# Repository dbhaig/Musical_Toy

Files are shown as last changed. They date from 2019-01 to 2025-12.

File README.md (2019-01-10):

# Musical Toy

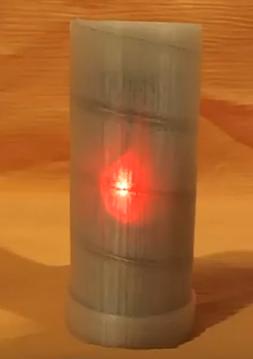
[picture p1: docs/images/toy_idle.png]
Toy in idle state

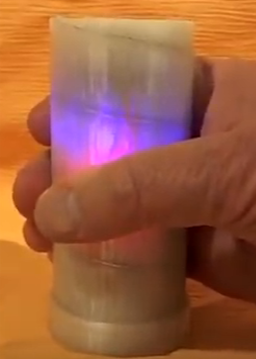
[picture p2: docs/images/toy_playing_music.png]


This repository contains the files needed to construct an inexpensive toy
that plays audio files when held. 

This toy was developed in response to a
request made from Makers Making Change:

https://www.makersmakingchange.com/project/conductive-touch-music-toy/

A video of the toy can be found here: https://www.youtube.com/watch?v=sac93CFT064

## Firmware

The toy uses an Arduino Nano to control a DFPlayer Mini MP3 player.  [Firmware Details](firmware/README.md)

## Bill of Materials

Item # | Description                                   | Qty | Source
-------|-----------------------------------------------|----------|-------
   1   | Arduino Nano (V3)                             |  1  | E Bay
   2   | DFPlayer Mini                                 |  1  | E Bay
   3   | 9V Battery Enclosure w/ Power Switch          |  1  | E Bay
   4   | Breadboard Friendly PCB Speaker - 8 Ohm, 0.2W |  1  | www.BuyaPi.ca / www.adafruit.com
   5   | 4GB - 32 GB SD Card                           |  1  | www.BuyaPi.ca
   6   | 9 Volt Battery                                |  1  |

## 3D Printed Parts

Item # | Description                                   
-------|-----------------------------------------------------------------------
   1   | Outer shell with embedded 24 AWG wire - acts a capacitive touch sensor [stl file](enclosure/stl_files/shell.stl)
   2   | Arduino Nano Holder [stl file](enclosure/stl_files/arduino_nano_clip.stl)
   3   | Clip to hold Speaker [stl file](enclosure/stl_files/speaker_clip.stl)
   4   | Frame to hold DFPlayer Mini, Nano frame and 9V enclosure [stl file](enclosure/stl_files/9V_surround.stl)
   5   | End Cap [stl file](enclosure/stl_files/cap.stl)

3D printed parts were designed to by printed using a 0.4mm nozzle. [Enclosure Details](enclosure/README.md)

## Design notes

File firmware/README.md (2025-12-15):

# Arduino Firmware

The firmware is written using the following libraries:

* ADCTouch by martin2250 - https://github.com/martin2250/ADCTouch 
* DFPlayer by DFRobot - https://github.com/DFRobot/DFRobotDFPlayerMini 

The firmware is fairly straight forward. The Arduino can be programmed using the IDE found here:
https://www.arduino.cc/en/main/software

The touch sensitivity of the toy can be adjusted by changing the value of the 
touch_ambient variable.

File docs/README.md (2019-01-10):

# Documentation

## Wiring Diagram

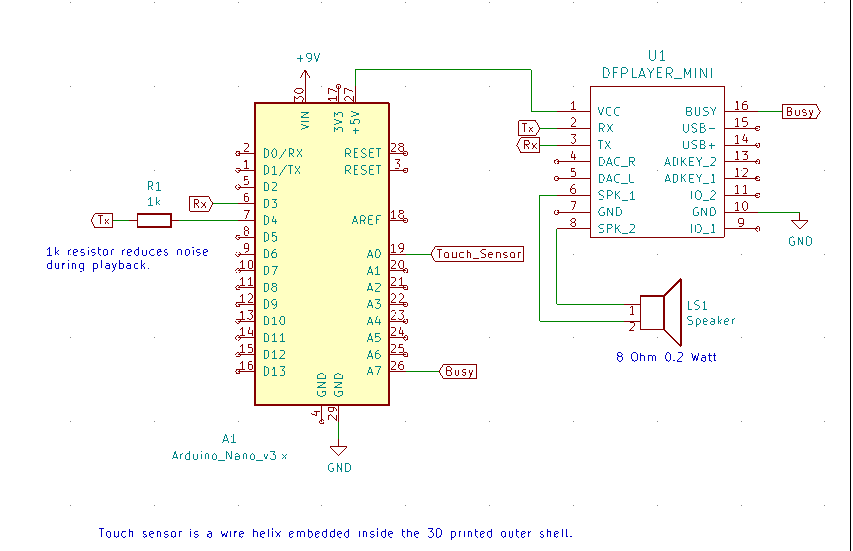
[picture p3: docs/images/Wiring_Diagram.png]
Wiring Diagram


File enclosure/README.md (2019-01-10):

# 3D Printed Parts

## Design Software

The 3D printed part were designed using OpenSCAD version 2015.03-2 (http://www.openscad.org/)

## Assembly

Exploded view:

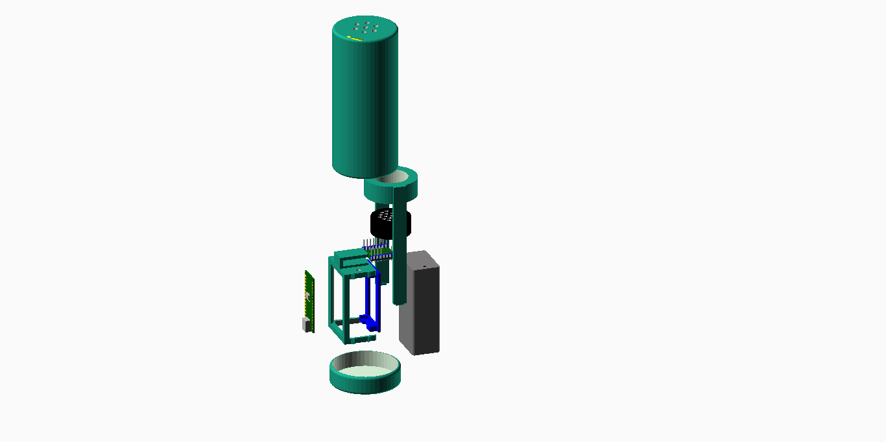
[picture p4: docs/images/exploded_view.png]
Exploded View


Interior Assembly:

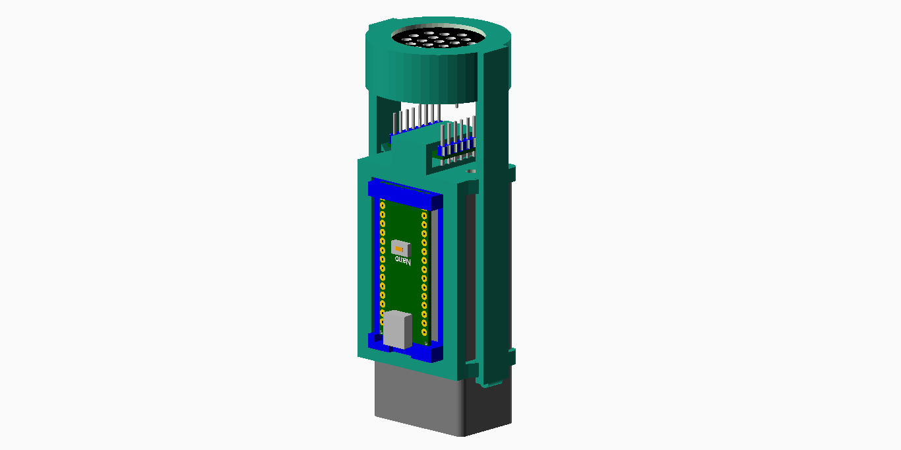
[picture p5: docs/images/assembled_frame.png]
Interior Assembly


The arduino nano holder (blue) should be glued to the frame (turquoise) using hot glue or super glue.

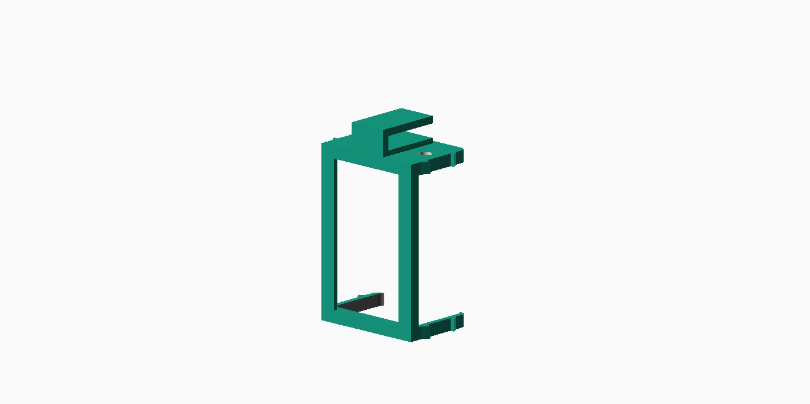
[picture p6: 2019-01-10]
docs/images/battery_clip+dfplayer_holder.png

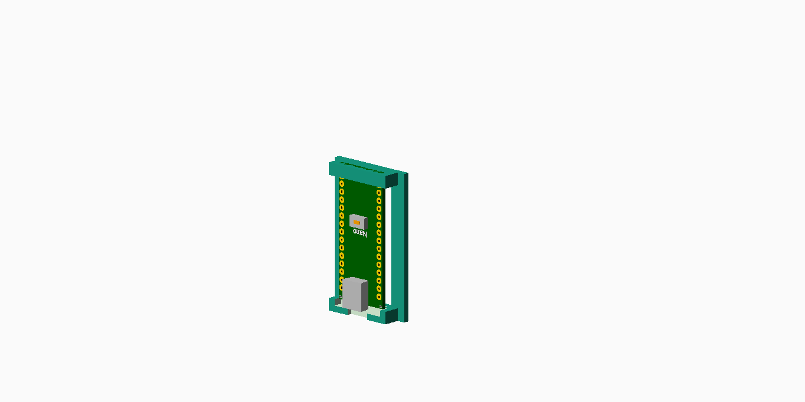
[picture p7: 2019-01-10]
docs/images/arduino_nano_holder2.png

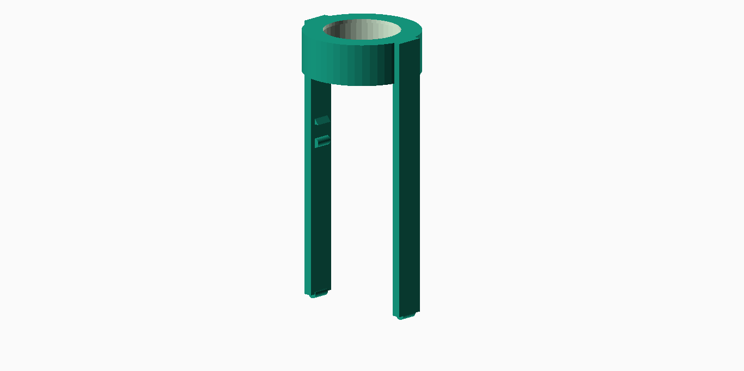
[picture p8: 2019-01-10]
docs/images/speaker_clip.png

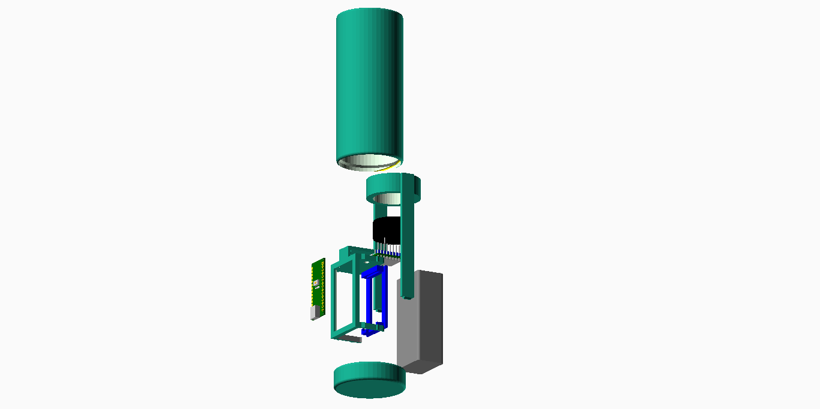
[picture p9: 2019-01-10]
docs/images/exploded_view2.png

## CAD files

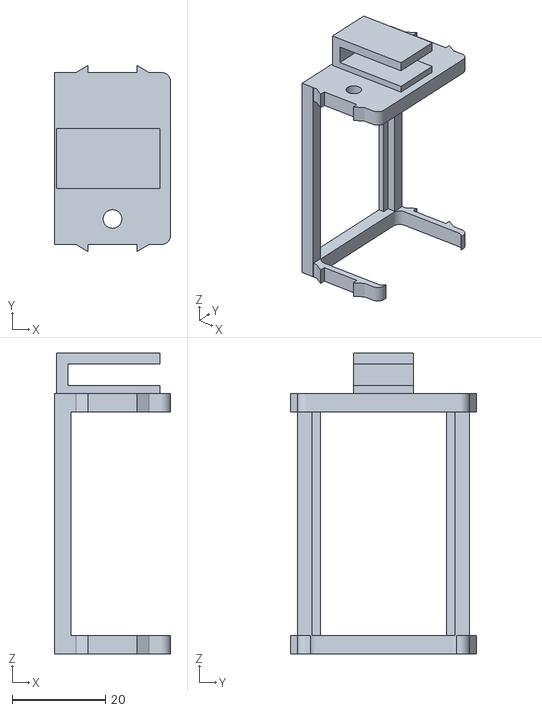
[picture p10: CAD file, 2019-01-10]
enclosure/stl_files/9V_surround.stl
25.0 x 40.0 x 64.7

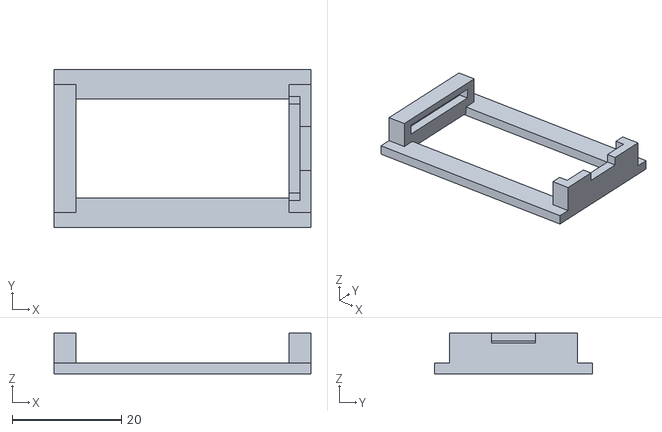
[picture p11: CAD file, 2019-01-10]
enclosure/stl_files/arduino_nano_clip.stl
47.1 x 29.0 x 7.50

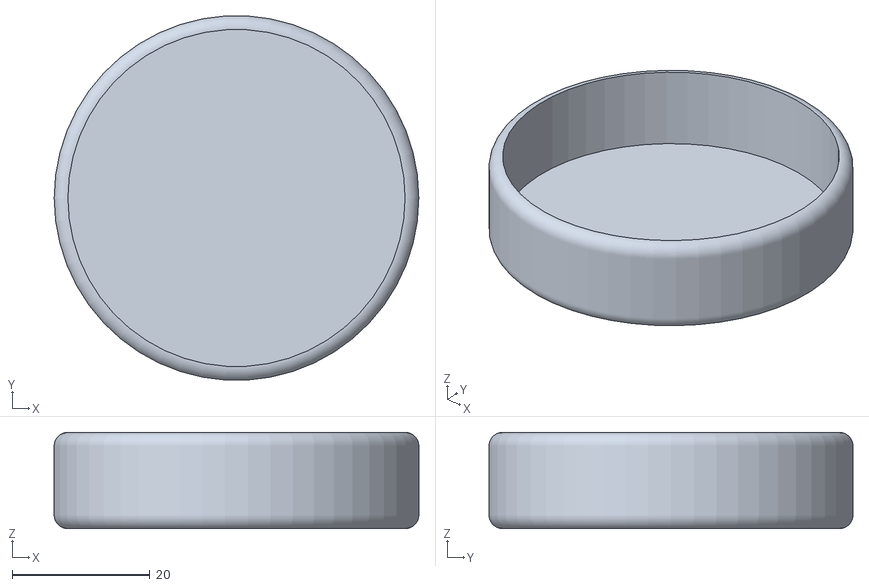
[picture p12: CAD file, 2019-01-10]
enclosure/stl_files/cap.stl
53.0 x 52.9 x 14.0

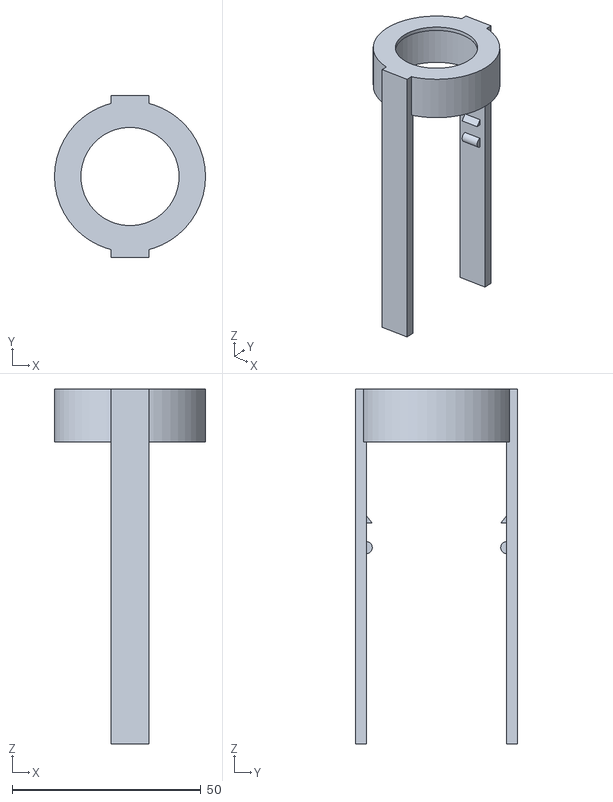
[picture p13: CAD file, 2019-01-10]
enclosure/stl_files/speaker_clip.stl
40.0 x 43.0 x 94.0

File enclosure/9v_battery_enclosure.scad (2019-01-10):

/* 9v_battery_enclosure.scad
 *
 *    OpenSCAD script to generate a  3D model for a 9V battery enclosure with switch
 *
 *    Copyright 2018 Don Haig (time4tux at gmail dot com)
 *
 *    GNU GPLv3 (See LICENSE for details) 
 *
 */
$fn = 50;

module 9V_enclosure() {

    l = 68.5;   // length of enclosure
    w = 33.4;   // width of enclosure
    h = 21.5;   // height of enclosure
    s_h = 1.6;  // height on/off switch above enclosure
    r = 2;      // corner radius


    color("grey")
    minkowski () {
        cube([h-2*r, w-2*r, l/2], center=true);
        cylinder(r=r, h=l/2);
    }

    color("red") translate([-0.6, 13, 51]) cylinder(r=0.6);
    color("black") translate([0.6, 13, 51]) cylinder(r=0.6);

    color("silver") translate([-h/2, -7, 43])  cube([s_h, 8, 3], center=true);

}

//9V_enclosure();

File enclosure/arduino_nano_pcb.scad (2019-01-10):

/* arduino_nano_pcb.scad
 *
 *    OpenSCAD script to generate a  3D model for the arduino nano Module 
 *
 *    Copyright 2018 Don Haig (time4tux at gmail dot com)
 *
 *    GNU GPLv3 (See LICENSE for details) 
 *
 */
$fn = 50;
use<straight_header.scad>

module arduino_nano_pcb() {

    pcb_l = 43.1;
    pcb_w = 18.1;
    pcb_h = 1.4;

    tol = 0;

    size = 1.8;
    font = "Liberation Sans";
    letter_height = pcb_h;

    module substrate () {
        difference() {
            color("darkgreen") cube([pcb_l, pcb_w, pcb_h], center=true);
        }
    }


    module pcb_name() {
        color("white") 
        translate([-1, 0, -0.5])
        rotate([0, 0, -90])
        linear_extrude(letter_height)
        text("Nano", size = size, font = font, halign = "center", valign = "center");
    }


    module mounting_holes() {

        d_e = 0.2;   // Distance of mounting holes from the edge
        h_r = 1.0/2;   // Radius of mounting holes

        translate([pcb_l/2 - h_r - d_e, pcb_w/2 - h_r - d_e, 0]) cylinder(r=h_r, h = 1.1*pcb_h, center = true);
        translate([-pcb_l/2 + h_r + d_e, pcb_w/2 - h_r - d_e, 0]) cylinder(r=h_r, h = 1.1*pcb_h, center = true);

        translate([pcb_l/2 - h_r - d_e, -pcb_w/2 + h_r + d_e, 0]) cylinder(r=h_r, h = 1.1*pcb_h, center = true);
        translate([-pcb_l/2 + h_r + d_e, -pcb_w/2 + h_r + d_e, 0]) cylinder(r=h_r, h = 1.1*pcb_h, center = true);
    }

    module pin_header_pads() {
        translate([-pcb_l/2 + 2.54/2, pcb_w/2 - 2.54/2, 0])
        header_pads(15, 1, pcb_h);
        translate([-pcb_l/2 + 2.54/2, -pcb_w/2 + 2.54/2, 0])
        header_pads(15, 1, pcb_h);
    }

    module pin_header_holes() {
        translate([-pcb_l/2 + 2.54/2, pcb_w/2 - 2.54/2, 0])
        header_holes(15, 1, pcb_h);
        translate([-pcb_l/2 + 2.54/2, -pcb_w/2 + 2.54/2, 0])
        header_holes(15, 1, pcb_h);
    }

    module mini_usb() {

        color("silver")
        translate([pcb_l/2 - 8, 0, 1.9*pcb_h])
        rotate([90, 0, 90])
        linear_extrude(9.1)
        polygon(points=[[-7.7/2,2], [7.7/2,2], [6.5/2,-2], [-6.5/2,-2]]);
    }

    module reset_button() {
        translate([-19.75+15.1, 0, pcb_h]) 
        union () {
            color("silver")
            cube([3.6, 6, 1.9], center=true);
            color("orange")
            cube([1.1, 2.4, 2.2], center=true);
        }
    }

    translate([0, 0, pcb_h/2]) {
        difference() {
            union() {
                substrate();
                translate([2.54, 0, 0]) pin_header_pads();
            }
            mounting_holes();
            translate([2.54, 0, 0]) pin_header_holes();
        }
        mini_usb();
        reset_button();
        pcb_name();
    }
}

module  arduino_nano_clip () {

    pcb_l = 43.1;
    pcb_w = 18.1;
    pcb_h = 1.4;

    module bottom_support(){
        difference() {
        translate([0, 0, -3]) cube([pcb_l +4, , 1.6*pcb_w, 2], center=true);
        translate([0, 0, -3]) cube([pcb_l, , pcb_w, 2.1], center=true);
        }
    }

    module other_end() {
        rotate([0, 0, 180])
        difference() {
            translate([0, 0, 0]) cube([4, , 1.3*pcb_w, 7], center=true);
            translate([-2, 0, 1]) cube([4.01, , 1.05*pcb_w, 1.5*pcb_h], center=true);
        }

    }
    module usb_end() {
        difference() {
            translate([0, 0, 0]) cube([4, , 1.3*pcb_w, 7], center=true);
            translate([0, 0, 4.2]) cube([4.01, , 0.45*pcb_w, 5], center=true);
            translate([-2, 0, 2.1]) cube([4.01, , 1.05*pcb_w, 2.5*pcb_h], center=true);
            translate([-1.5, 0, 0]) cube([3.01, , 0.9*pcb_w, 3], center=true);
        }
    }

    translate([0, 0, 0]) bottom_support();
    translate([pcb_l/2, 0, 0]) usb_end();
    translate([-pcb_l/2, 0, 0]) other_end();
}

    module arduino_nano_clip_footprint() {
        translate([0, 0, -3]) cube([48.1, , 1.7*18.1, 2.4], center=true);
    }

//arduino_nano_clip();
//translate([0, 0, 0.5]) arduino_nano_pcb();

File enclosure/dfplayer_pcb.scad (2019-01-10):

/* dfplayer_mini_pcb.scad
 *
 *    OpenSCAD script to generate a  3D model for the DFPlayer-Mini Module 
 *
 *    Copyright 2018 Don Haig (time4tux at gmail dot com)
 *
 *    GNU GPLv3 (See LICENSE for details) 
 *
 */
$fn = 50;
use<straight_header.scad>

module dfplayer_pcb() {

    pcb_l = 20.5;
    pcb_w = 20.5;
    pcb_h = 1.0;

    l_r = 1.45;  // Radius of large mounting holes
    tol = 0;

    size = 1;
    font = "Liberation Sans";
    letter_height = 1;

    module substrate () {
        difference() {
            color("darkgreen") cube([pcb_l, pcb_w, pcb_h], center=true);
            translate([-pcb_l/2, 0, -1]) cylinder(r=1, h=2);
        }
    }


    module pcb_name() {
        color("white") 
        translate([-7, 0, -0.5])
        rotate([0, 0, 90])
        linear_extrude(letter_height)
        text("DFPlayer Mini", size = size, font = font, halign = "center", valign = "center");
    }


    module header_holes() {

        d_e = 0.4;   // Distance of mounting holes from the edge
        h_r = 0.35;     // Radius of header holes

        for(x  = [0 : 7]) {
        translate([-pcb_l/2 + d_e + h_r + x*2.7, -pcb_w/2 + d_e + h_r, 0]) cylinder(r=h_r, h = 1.1*pcb_h, center = true);
        }
    }

    module headers() {
        translate([-pcb_l/2 + 2.54/2, pcb_w/2 - 2.54/2, -9.0])
        straight_header(8, 1);
        translate([-pcb_l/2 + 2.54/2, -pcb_w/2 + 2.54/2, -9.0])
        straight_header(8, 1);
    }

    module socket() {
        translate([-3.1, -pcb_l/2+3.1, pcb_h/2]) color("silver") cube([14.1, 14.7, 2.0]);
    }

    translate([0, 0, pcb_h/2]) {
        socket();
        substrate();
        headers();
        pcb_name();
    }
}

module  dfplayer_clip () {

    l = 20.5;
    w = 13;
    h = 2.4;

        translate([0, 0,  3.5]) cube([l, w, h], center=true);
        translate([0, 0, -3.5]) cube([l, w, h], center=true);
        translate([-l/2-h/2+0.65, 0, 0]) cube([2.4, w, 2.4+7], center=true);
}

//dfplayer_clip();
//dfplayer_pcb(); 

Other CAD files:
enclosure/helix.scad
enclosure/speaker.scad
enclosure/touch_toy.scad

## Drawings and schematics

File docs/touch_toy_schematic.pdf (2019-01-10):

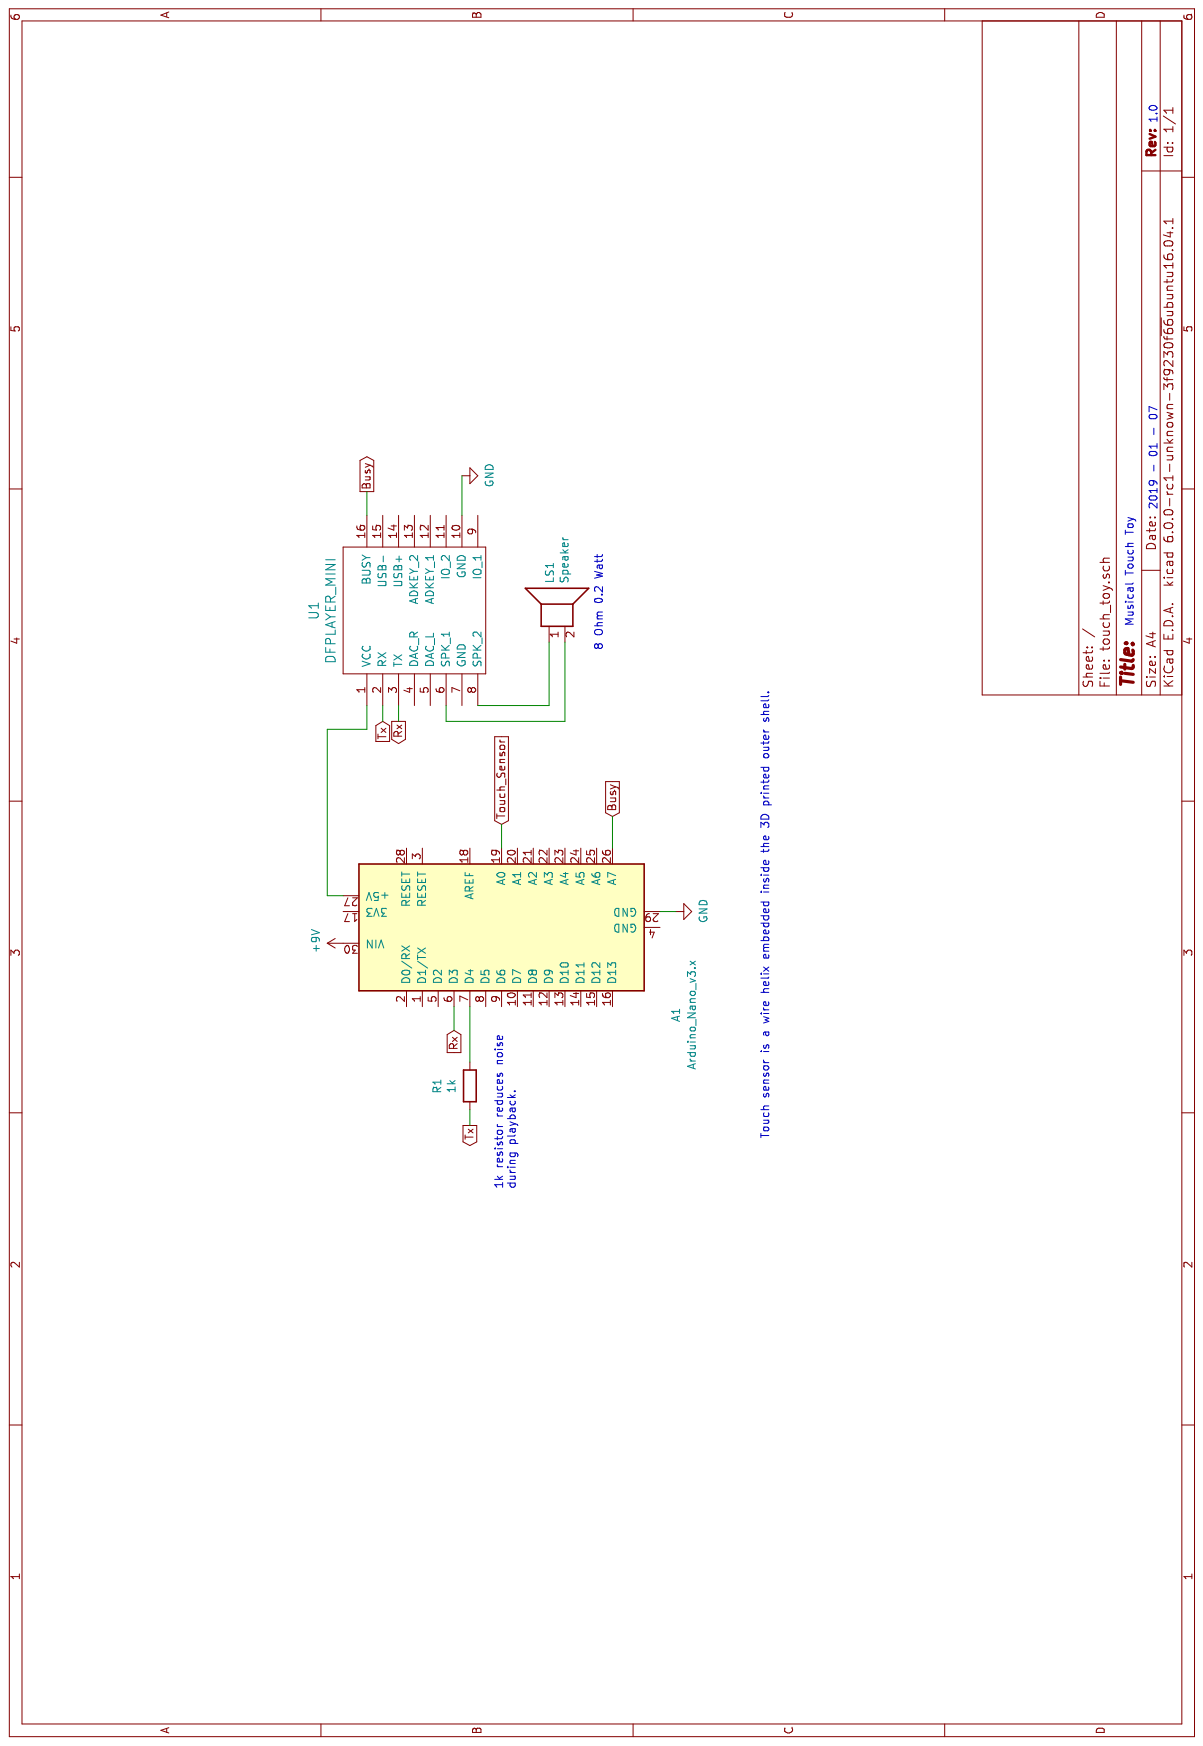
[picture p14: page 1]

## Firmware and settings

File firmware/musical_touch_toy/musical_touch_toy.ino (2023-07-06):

/* musical_touch_toy.ino
 *
 *    Firmware for musical touch toy
 *
 *    Copyright 2023 Don Haig (time4tux at gmail dot com)
 *
 *    GNU GPLv3 (See LICENSE for details) 
 *
 */
#include "ADCTouch.h"
#include "SoftwareSerial.h"
#include "DFRobotDFPlayerMini.h"

DFRobotDFPlayerMini dfplayer;

SoftwareSerial player_uart(3, 4); // rx, tx

bool player_busy();
bool touch();

int touch_ambient;

void setup() {
    touch_ambient = 572;    // Adjust this value to alter sensitivity to touch

    pinMode(A7, INPUT);       // Connected to dfplayer BUSY pin

    player_uart.begin(9600); 

    if (!dfplayer.begin(player_uart, false)) 
       Serial.println("Ignoring dfplayer.begin() error");

    Serial.begin(115200);
    Serial.println(ADCTouch.read(A0, 500),DEC);

    dfplayer.volume(30);   // Can be set from 0 to 30
}


void loop() {
    if (!player_busy() && touch()) dfplayer.next();
    if (player_busy() && !touch()) dfplayer.stop();

    Serial.println(ADCTouch.read(A0, 500),DEC);
}

bool player_busy() {
    if (analogRead(A7) < 500) return true;
    return false;
}

#define touchThreshold 6 

bool touch() {
    if ((ADCTouch.read(A0) - touch_ambient) > touchThreshold) return true; 
    return false;

}

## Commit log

2019-01-10 Initial prototype release.
    [9V_surround.stl, 9v_battery_enclosure.scad, arduino_nano_clip.stl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]
2025-12-15 Update README.md
    Remove references to amake as arduino-cli is now available and more capable.
